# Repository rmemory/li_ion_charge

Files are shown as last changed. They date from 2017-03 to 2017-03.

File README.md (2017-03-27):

This repo contains the schematic and PCB layout for a battery charge controller board. 

The intent of this board is to provide a simple controller to connect a USB port to a discrete single cell recharagable Lithum Ion battery. The USB port will be used to provide power input only (~4.5v), and consequently the USB data port will not be used. This board will also be capable of providing power to a CPU board (3.3V). 

The charge controller chip selected for this board is the Microchip MCP73834. The 834 has been selected due to the optional timer functionality over the 833. The timer provides some protection to no unmonitored, unattended charging over a long period of time.

http://ww1.microchip.com/downloads/en/DeviceDoc/22005a.pdf

Its benefits include the following:

* This chip adhers to all of the power standards of the USB bus and also intended primarily to charge a lithium ion battery.

* Integrated pass (controlling) transistor. This has the advantage of not requiring a seperate external discrete part. The potential slight disadvantage of not being able to control the exact characteristics of the transistor are not a problem in this particular case.

* Integrated current sense.

* The reverse discharge protection feature is nice but in this case not a priority because only a USB connector input (4.2 - 4.5v) will be supported as opposed to two open wires (which in theory could be connected to anything allowing the battery to be discharged).

* Preconditioning of a deeply discharged battery is another nice feature to prevent overheating (and fire!) of the battery during recharge. If a Li-ion battery is deeply discharged (for example, to below 3 V) a small “pre-conditioning” charge of around 10% of the full-charge current is applied. This prevents the cell from overheating until such a time that it is able to accept the full current of the constant-current phase. In reality, this phase is rarely needed because most modern mobile devices are designed to shut down while there’s still some charge left because deep discharge, like overcharging, can damage the cell. With that said, note the external heat sensing thermistor is not used in this design.

* The sample application circuit specified in the data sheet will be used with minor modifications.

* A linear drop out mode is also useful as the internal resistance of the battery increases and battery output voltage degrades.

* The MSOP 10 package will be used to allow for hand soldering.

A designer's guide to lithium battery charging can be found here:

https://www.digikey.com/en/articles/techzone/2016/sep/a-designer-guide-fast-lithium-ion-battery-charging

Circut design notes:
======================

The "typical application" circuit provided on the data sheet will provide the core of the circuit design.

A regulated current of 500 mA will be used, and thus according to the equation Ireg = 1000V/Rprog, a value of 2k ohms for the Rprog will be used.

A standard USB Type A connector will be used. 

A slightly larger 4.7 uF capacitor, with a 1206 foot print will be used to accomodate for the 500 mA charging current. The 4.7 uF caps are available in an 0805 size, but they tend to be more expensive and more difficuclt to find.

Rudimentary reset functionality will be provided via a jumper.

Via Stitching (i.e. adding of extra vias between planes) reduces inductance between planes. All conductors have some inductance due to the magnetic field due to the current flowing. The inductance will increase as signal frequency increases. For example, a square wave (data) has many high frequency signals. One via will create a small inductor. More vias reduce the inductance by putting inductors in parallel, thus reducing overall impedance of the signals between planes, thus making sure the signal isn't distorted between planes. Via stitching also helps heat dissapation. 

General KiCad Workflow notes:
=============================

* Add parts to project specific library as needed

* Draw schematic, with values

* Annotate schematic

* Run ERC, address any critical errors

* Generate netlist

* Run CvPcb to associate parts in schematic with footprints, creating footprints where necessary

* PCBNew for layout
  * Read current net list
  * Mode Footprint button selected (third from the right in the top bar). Then right click on the stack of footprints and select "Glob Move and Place->Move All modules"

The overheating feature will not be used, and thus the thermistor will be replaced by a fixed 10k value.

BOM Generation notes:
=====================

http://og2k.com/content/how-generate-bill-materials-bom-kicad

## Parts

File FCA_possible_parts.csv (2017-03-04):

InputV-Min | InputV-Max | Topology | ChargerType | BatteryVoltage | Functions | ChargeCurrent(Max) | PKGtypeMPN | Parts.ioLink | DatasheetLink | Datasheet | Notes
4.5 | 24 | Linear | USB/WW | 8.2V | Double Cell | EXT | SOIC | LM3622 | Search | http://www.ti.com/lit/ds/symlink/lm3622.pdf | LM3622 Datasheet | External Pass Transistor
5 | 22 | Linear | USB/WW | 4.1V | Single Cell | EXT | uMax | MAX1679 | Search | http://images.ihscontent.net/vipimages/VipMasterIC/IC/MAXM/MAXMS00880/MAXMS00880-1.pdf | MAX1679 Datasheet | No Inductor required, external PMOS
6 | 28 | Switcher - Buck | WW | 8.2V | Double Cell | EXT | QSOP | MAX1873 | Search | http://datasheets.maximintegrated.com/en/ds/MAX1873.pdf | MAX1873 Datasheet | Multi cell, not USB compatible
4.35 | 16 | Switcher - Buck | USB/WW | 8.2V | Double Cell | 2000 | QFN | BQ24100 | Search | http://www.ti.com/lit/ds/slus606o/slus606o.pdf | BQ24100 Datasheet | Synchronous switcher, load monitoring,3 charge modes.
4.5 | 5 | Linear | USB/WW | 4.2V | Single Cell | 500 | WSON | LM3658 | Search | http://www.ti.com/lit/ds/snvs328e/snvs328e.pdf | LM3658 Datasheet | Selectable charge currents, 5 charge modes. Also acts as LDO when no battery present.
3.75 | 6 | Linear | USB | 4.2V | Single Cell | 500 | SOT23-5 | MCP73812 | Search | http://ww1.microchip.com/downloads/en/DeviceDoc/22036b.pdf | MCP73812 Datasheet | Selectable charge currents, only 2 caps and a resistor required external
3.75 | 6 | Linear | USB | 4.2V | Single Cell | 1000 | MSOP | MCP73833 | Search | http://ww1.microchip.com/downloads/en/DeviceDoc/22005b.pdf | MCP73833 Datasheet | 2 status LEDs and a thermal compensation circuit
4.5 | 6.5 | Linear | USB | 4.2V | Single Cell | 150 | SOT23-5 | LTC4054-4.2 | Search | http://cds.linear.com/docs/en/datasheet/4054l42fa.pdf | LTC4054-4.2 Datasheet | Meant for low capacity cells like li-ion coin cells
4.55 | 8 | Linear | USB | 4.2V | Single Cell | EXT | SOT23-5 | LTC1734 | Search | http://cds.linear.com/docs/en/datasheet/1734fs.pdf | LTC1734 Datasheet | External Pass Transistor, 1% accuracy, programmable charge current.
3.8 | 5.5 | Linear | USB/WW | 4.2V | Single Cell | 1500 | DFN | LTC4067 | Search | http://cds.linear.com/docs/en/datasheet/4067f.pdf | LTC4067 Datasheet
4.7 | 22 | Switcher - Buck | USB/WW | 4.2V | Single Cell | EXT | SOIC | LTC4002ES8-4.2 | Search | http://cds.linear.com/docs/en/datasheet/4002f.pdf | LTC4002ES8-4.2 Datasheet
3.5 | 12 | Linear | USB | 4.2V | Single Cell | 1000 | MSOP | BQ24090 | Search | http://www.ti.com/lit/ds/symlink/bq24090.pdf | BQ24090 Datasheet | The bq2409x has a single power output that charges the battery. A system load can be placed in parallel with the battery as long as the average system load does not keep the battery from charging fully during the 10-hour safety timer.
4.5 | 12 | Linear | USB/WW | 4.2V | Single Cell | 1500 | MSOP | ADP2291 | Search | http://www.analog.com/media/en/technical-documentation/data-sheets/ADP2291.pdf | ADP2291 Datasheet | External Pass Transistor
4.25 | 6 | Linear | USB/WW | 4.2V | Single Cell | 800 | SOT-89-5 | XC6802 | Search | http://www.torex.co.jp/english/products/battery_charge_ic/data/XC6802.pdf | XC6802 Datasheet | Temperature overheat protection because of small size.
4.5 | 15 | Linear | USB/WW | 4.2V | Single Cell | EXT | SOIC | BQ2057CSN | Search | http://www.ti.com/lit/ds/symlink/bq2057c.pdf | BQ2057CSN Datasheet | External Pass Transistor
We are selecting the MCP73833 which is line 8
We are looking for USB (4.5v)
Lithium support (3.7)
High current (2A) not necessary
Packaging is a concern (not QFN)
Linear ones are the least expensive

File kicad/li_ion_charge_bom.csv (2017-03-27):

Reference | Value | Footprint | Datasheet | MPN
D103 | LED | LEDs:LED_0805 | https://media.digikey.com/pdf/Data%20Sheets/Lite-On%20PDFs/LTST-S220GKT.pdf | LTST-S220GKT
D101 | NOPOP | LEDs:LED_0805
D102 | LED | LEDs:LED_0805 | https://media.digikey.com/pdf/Data%20Sheets/Lite-On%20PDFs/LTST-S220GKT.pdf | LTST-S220GKT
R102 | 470 | Resistors_SMD:R_0805_HandSoldering |  | RMCF0805JT470R
R103 | NOPOP | Resistors_SMD:R_0805_HandSoldering
R101 | 470 | Resistors_SMD:R_0805_HandSoldering |  | RMCF0805JT470R
U101 | MCP73834 | Housings_SSOP:MSOP-10_3x3mm_Pitch0.5mm | http://ww1.microchip.com/downloads/en/DeviceDoc/22005a.pdf | MCP73834-FCI/UN
R106 | 2k | Resistors_SMD:R_0805_HandSoldering |  | ERJ-6ENF2001V
R105 | 10k | Resistors_SMD:R_0805_HandSoldering |  | RC0805JR-0710KL
C102 | 4.7u | Capacitors_SMD:C_1206_HandSoldering | http://www.yuden.co.jp/productdata/catalog/en/mlcc_all_e.pdf | LMK316B7475KL-T
P103 | CONN_01X02 | Pin_Headers:Pin_Header_Straight_1x02_Pitch2.00mm |  | M20-9990246
C101 | 4.7u | Capacitors_SMD:C_1206_HandSoldering | http://www.yuden.co.jp/productdata/catalog/en/mlcc_all_e.pdf | LMK316B7475KL-T
P101 | USB_B | li_ion_charge_library:USB_Micro-B_10118193-0001LF | http://portal.fciconnect.com/Comergent//fci/drawing/10118193.pdf | 10118193-0001LF
R104 | 1k | Resistors_SMD:R_0805_HandSoldering |  | RC0805JR-071KL
P102 | CONN_01X02 | Pin_Headers:Pin_Header_Straight_1x02_Pitch2.54mm |  | M20-9990246
R108 | NOPOP | Resistors_SMD:R_0805_HandSoldering
R107 | NOPOP | Resistors_SMD:R_0805_HandSoldering
R109 | NOPOP | Resistors_SMD:R_0805_HandSoldering
J101 | CONN_01X02 |  | http://www.jst-mfg.com/product/pdf/eng/ePH.pdf | B2B-PH-K-S(LF)(SN)

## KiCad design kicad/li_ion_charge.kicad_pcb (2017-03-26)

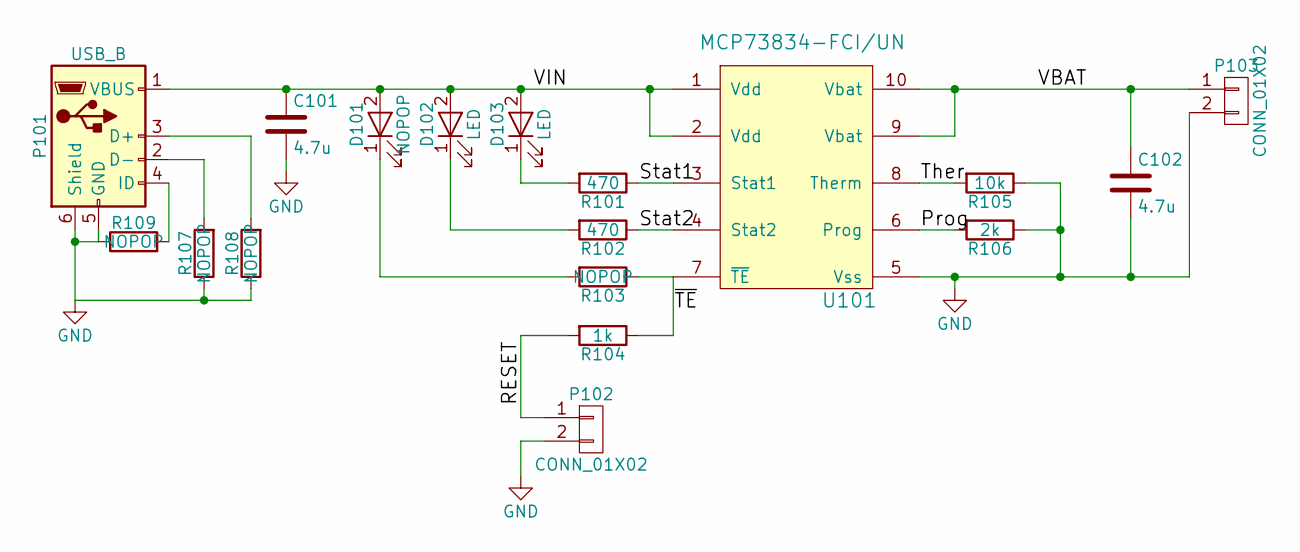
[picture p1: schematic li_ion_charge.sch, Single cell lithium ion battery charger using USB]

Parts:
C101, C102: 4.7u; C_1206_HandSoldering
D101: NOPOP; LED_0805
D102, D103: LED; LED_0805
P101: USB_B; USB_Micro-B_10118193-0001LF; MPN 10118193-0001LF
P102, P103: CONN_01X02; Pin_Header_Straight_1x02_Pitch2.54mm
R101, R102: 470; R_0805_HandSoldering
R103, R107, R108, R109: NOPOP; R_0805_HandSoldering
R104: 1k; R_0805_HandSoldering
R105: 10k; R_0805_HandSoldering
R106: 2k; R_0805_HandSoldering
U101: MCP73834-FCI/UN; MSOP-10_3x3mm_Pitch0.5mm

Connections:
/Prog: R106.2, U101.6 (Prog)
/RESET: P102.1, R104.2
/Stat1: R101.1, U101.3 (Stat1)
/Stat2: R102.1, U101.4 (Stat2)
/Ther: R105.2, U101.8 (Therm)
/VBAT: C102.1, P103.1, U101.9 (Vbat), U101.10 (Vbat)
/VIN: C101.1, D101.2 (A), D102.2 (A), D103.2 (A), P101.1 (VBUS), U101.1 (Vdd), U101.2 (Vdd)
/~TE: R103.1, R104.1, U101.7 (~TE)
GND: C101.2, C102.2, P101.5 (GND), P101.6 (Shield), P102.2, P103.2, R105.1, R106.1, R107.1, R108.1, R109.1, U101.5 (Vss)
unnamed: D101.1 (K), R103.2
unnamed: D102.1 (K), R102.2
unnamed: D103.1 (K), R101.2
unnamed: P101.2 (D-), R107.2
unnamed: P101.3 (D+), R108.2
unnamed: P101.4 (ID), R109.2

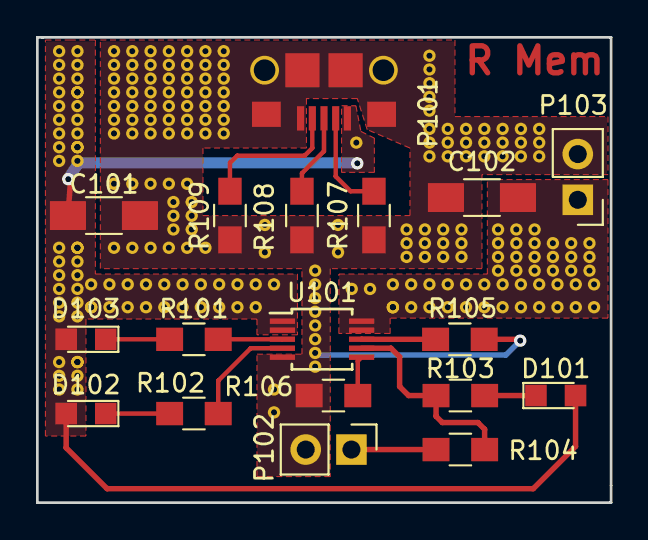
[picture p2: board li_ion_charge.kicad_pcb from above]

Board: 2 copper layers, 31.9 x 25.9 mm, 18 parts (0 on the bottom side), 15 nets.

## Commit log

2017-03-04 initial commit of empty kicad project
    [li_ion_charge.kicad_pcb, li_ion_charge.sch]
2017-03-04 Add library for MCP73834 part and add it to schematic
    [li_ion_charge.sch]
2017-03-05 Add a section in the README for circuit design notes
2017-03-05 Added notes to README regarding regulated current and cap values
2017-03-05 Initial implementation of schematic with values
    [li_ion_charge.sch]
2017-03-05 Add KiCad workflow notes
2017-03-05 Add footprint associations usinb CvPcb
    [li_ion_charge.sch]
2017-03-07 Update to vertical connector footprints and start initial layout
    [li_ion_charge.kicad_pcb]
2017-03-07 Add a more kicad notes
2017-03-07 Minor update to schematic after adding initial layout
    [li_ion_charge.sch]
2017-03-08 First iteration of complete layout
    [li_ion_charge.kicad_pcb]
2017-03-08 Second iteration of the layout; added several net labels as well
    [li_ion_charge.kicad_pcb, li_ion_charge.sch]
2017-03-09 Add initial USB micro B footprint
    [li_ion_charge.sch]
2017-03-09 Add datasheet for USB to schematic
    [li_ion_charge.sch]
2017-03-11 change the schematic to use a micro USB part, and update netlist and layout accordingly
    [li_ion_charge.kicad_pcb, li_ion_charge.sch]
2017-03-12 Adjust footprint of Micro USB to match the datasheet
    [li_ion_charge.kicad_pcb]
2017-03-12 Final USB footprint and added a label to schematic
    [li_ion_charge.kicad_pcb, li_ion_charge.sch]
2017-03-12 Update schematic and netlist to include a new nopop resistor, and this should be close to what the final part placement on the layout should look like
    [li_ion_charge.kicad_pcb, li_ion_charge.sch]
2017-03-12 First iteration of adding power planes and initial traces. Still need to add osh-park defaults and address ERC errors
    [li_ion_charge.kicad_pcb]
2017-03-14 Add data sheet for MCP738334
    [li_ion_charge.kicad_pcb]
2017-03-15 Add initial osh part design rule defaults
    [li_ion_charge.kicad_pcb]
2017-03-16 Front side planes and traces added
    [li_ion_charge.kicad_pcb]
2017-03-19 add power planes to back side
    [li_ion_charge.kicad_pcb]
2017-03-21 cleanup of zones, added zone for power from Vin pin, and initial edge cuts of board
    [li_ion_charge.kicad_pcb]
2017-03-22 add a couple vias
    [li_ion_charge.kicad_pcb]
2017-03-25 add stitching via footprint
    [li_ion_charge.kicad_pcb]
2017-03-26 Add gerbers, and order boards from Osh Park
    [li_ion_charge-B.Cu.gbr, li_ion_charge-B.Mask.gbr, li_ion_charge-B.SilkS.gbr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]
2017-03-26 Update README.md to include notes for BOM generation
2017-03-27 initial BOM
    [li_ion_charge.sch, li_ion_charge_bom.csv]
2017-03-27 Minor schematic change
    [li_ion_charge.sch]
